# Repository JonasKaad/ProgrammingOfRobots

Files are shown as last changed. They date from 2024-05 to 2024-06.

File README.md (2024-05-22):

# Garage - Digital Twin

GitHub page for the "Programming of robots and other physical devices" project on the Software Engineering Master (elective) @ SDU F24

## Project

The project concerns itself with IoT and Digital Twins.

In it we have to design a physical and virtual representation of any given thing of our choice. We chose to design a garage. The specific requirements to the physical and virtual representation are as follows:

- Physical: ESP32 D1 Mini + Sensors/Actuators + 3D printing
- Virtual: Unity
- Communication: Wireless (UDP)

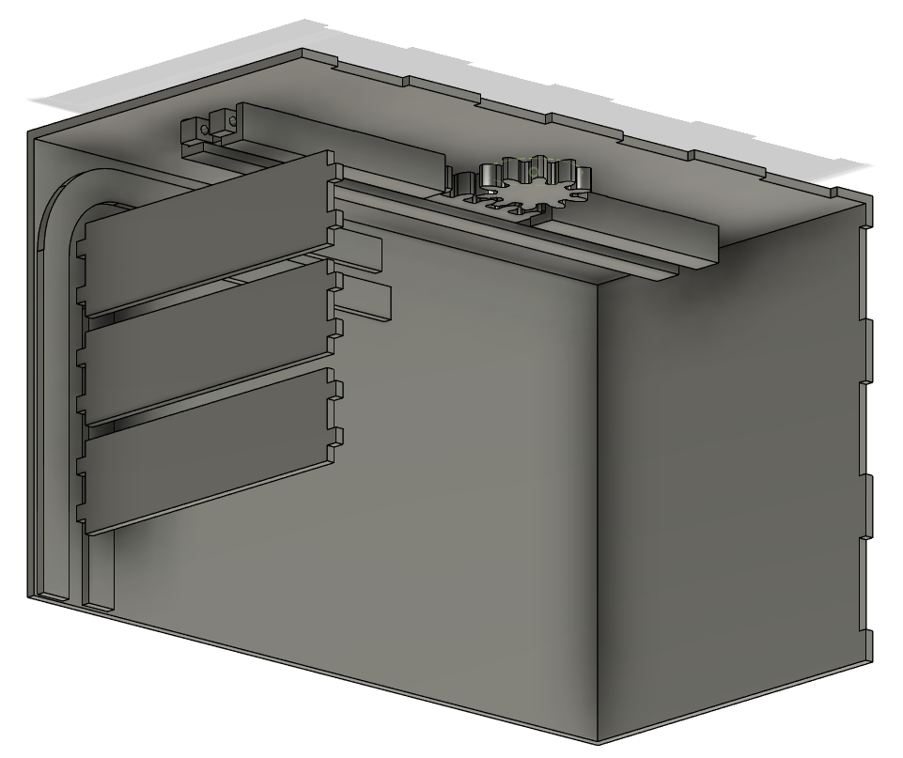
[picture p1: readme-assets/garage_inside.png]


## Repository

This repository contains all parts of the project:

- `src/`: C++ code for interacting with the ESP32 and the sensors, actuators, keypad and motors.
- `Unity/GarageTwin/`: All code related to the virtual representation of the digital twin, created in Unity
- `models/`: All 3D printed models, laser cut designs as well as a part lists to recreate the whole project.

## Authors

- [Jonas Solhaug Kaad](https://github.com/JonasKaad)
- [Victor Andreas Boye](https://github.com/VictorABoye)
- [Sebastian Christensen Mondrup](https://github.com/SebMon)
- [Alexander Vinding Nørup](https://github.com/AlexanderNorup)

**Supervisor**: Bjarke Kristian Maigaard Kjær Pedersen: bkp@mmmi.sdu.dk

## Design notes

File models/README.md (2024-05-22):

# Recreation of the garage


To recreate this project, you will need to 3D print the required parts, laser cut the garage and obtain

- `3DPrints/`: Contains all the `.STL` files that you need to 3D print.
- `LasercutDesigns/`: Contains all `.SVG` files that need to be lasercut. The design can be seen below
- All the electronic & hardware parts needed can be found below, with links to ArduinoTech, Harald Nyborg and Bauhaus.

## Electronic & hardware parts

- [ESP 32](https://arduinotech.dk/shop/live-d1-mini-esp32-development-board-based-esp8266/)
- [Breadboard](https://arduinotech.dk/shop/breadboard-830-points/)
- [DC Motor](https://arduinotech.dk/shop/n20-micro-metal-gear-motor/)
- [Motor Driver](https://arduinotech.dk/shop/mx1508-dc-motor-driver-module/)
- [LCD Screen](https://arduinotech.dk/shop/lcd-1602-16x2-w-pinheader/)
  - [LCD I2C Serial Interface](https://arduinotech.dk/shop/lcd-serial-interface/)
- [Battery Holder 4x AA](https://arduinotech.dk/shop/battery-holder-4-x-aa/)
- [4x AA Batteries](https://www.harald-nyborg.dk/kameda-alkaline-batteri-aa-10-pak)
- 12x [Buttons](https://arduinotech.dk/shop/switch-tactile-push-button-6x6x7mm/)
- [Potentiometer](https://arduinotech.dk/shop/potentiometer/)
- Cables
  - [Male-to-Male](https://arduinotech.dk/shop/65-stk-jump-wire-for-breadboard-and-arduino/)
  - [Male-to-Female](https://arduinotech.dk/shop/dupont-wire-30cm/)
- [3mm Screw](https://www.bauhaus.dk/gevindsskrue-uh-3x16)

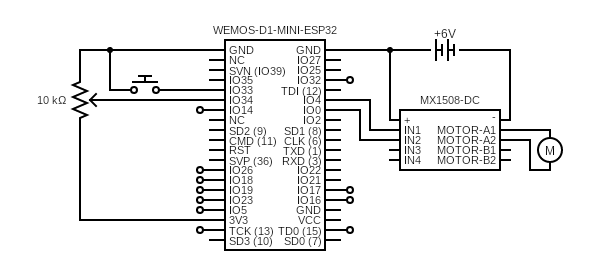
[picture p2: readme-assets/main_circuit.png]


## Laser cut designs

- Doors:

  

- Back:

  

- Roof:

  

- Left side:

  

- Right side:



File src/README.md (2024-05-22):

# Garage

## Pins

Below are the pins used on the ESP32 to connect to the keypad, screen and motors.

### Garage and motors

- POTENTIOMETER = 34
- DOOR_OPEN = 12
- DOOR_CLOSE = 27

### Keypad

- ZERO_PIN = 16
- ONE_PIN = 17
- TWO_PIN = 5
- THREE_PIN = 14
- FOUR_PIN = 23
- FIVE_PIN = 32
- SIX_PIN = 19
- SEVEN_PIN = 33
- EIGHT_PIN = 18
- NINE_PIN = 15
- RESET_PIN = 13
- ENTER_PIN = 26

### LCD Screen

- GND = Ground
- VCC = VCC
- SDA = 21
- SCL = 22

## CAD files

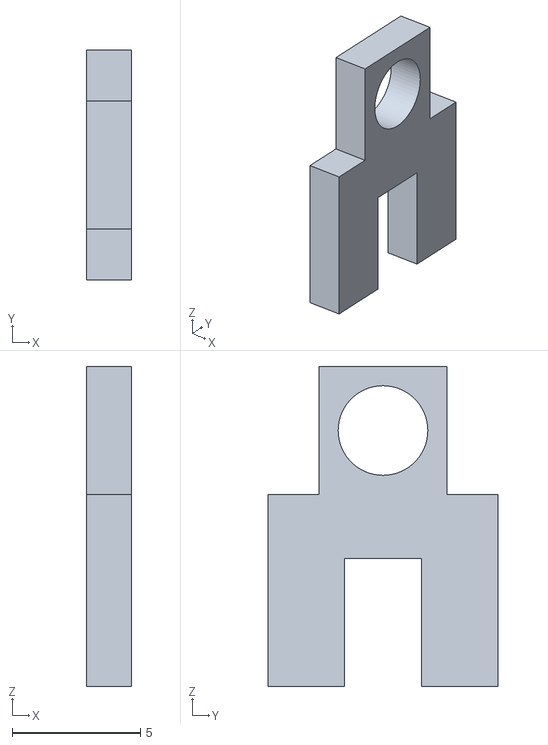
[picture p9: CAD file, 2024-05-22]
models/3DPrints/attachments/door_grapper.stl
1.75 x 9.00 x 12.5

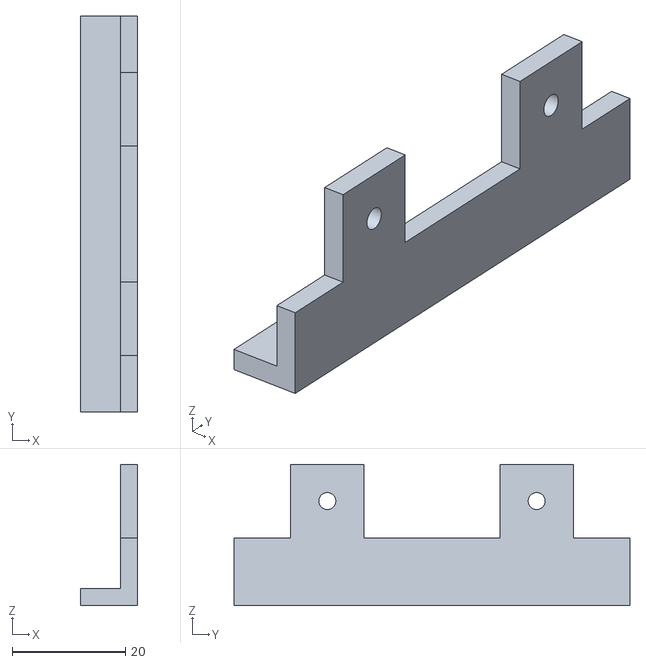
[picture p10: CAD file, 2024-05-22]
models/3DPrints/garage_bar/LBar_short.stl
10.0 x 70.0 x 25.0

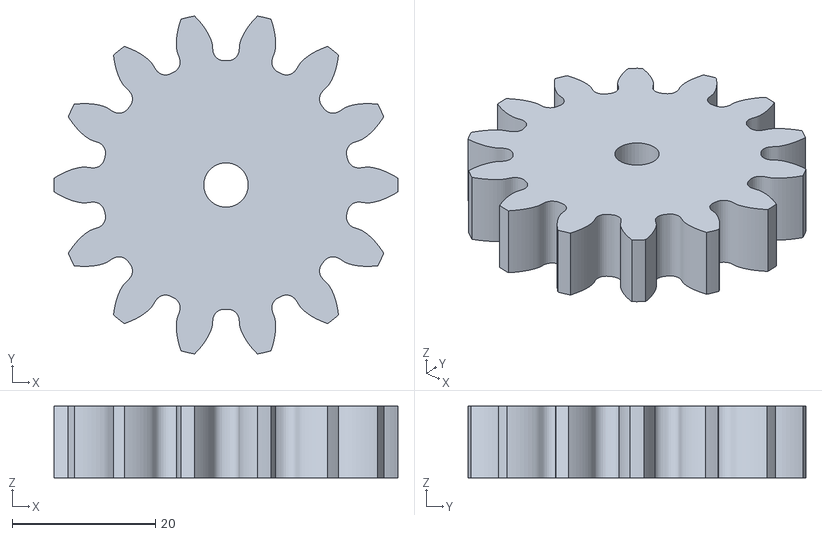
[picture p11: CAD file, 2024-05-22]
models/3DPrints/gears/potentiometer_gear.stl
48.0 x 47.2 x 10.0

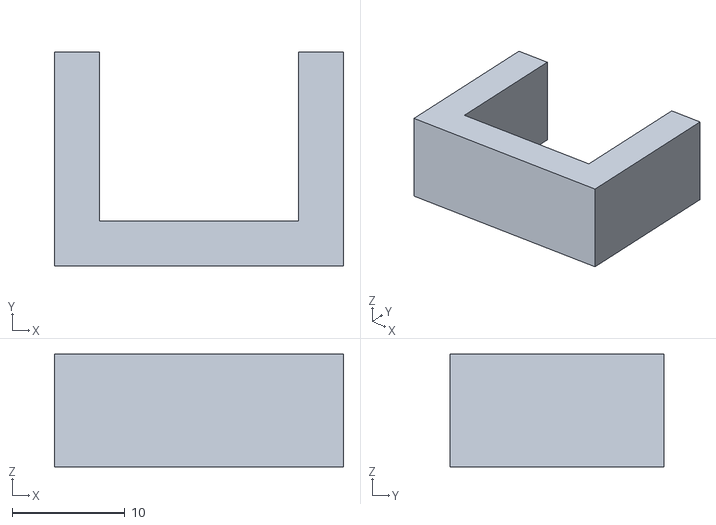
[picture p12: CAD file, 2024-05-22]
models/3DPrints/supports/potentiometer_casing.stl
25.6 x 19.0 x 10.0

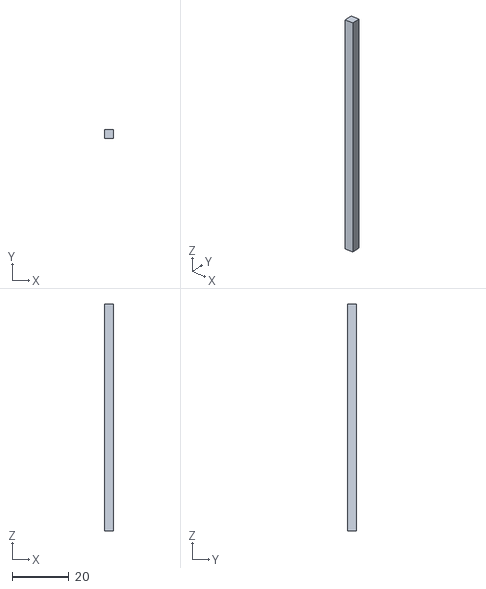
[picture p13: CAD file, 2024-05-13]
Unity/GarageTwin/Assets/Gears/WormDrive/long_stick.obj
3.00 x 3.00 x 80.0

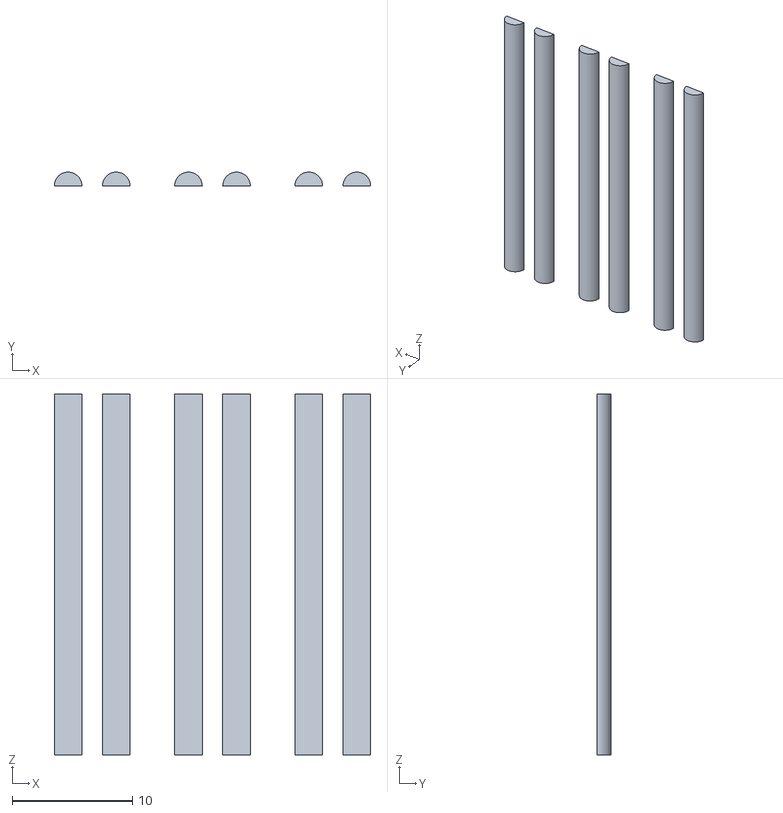
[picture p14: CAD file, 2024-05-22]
models/3DPrints/attachments/external_sticks_for_LBar.stl
26.3 x 1.15 x 30.0

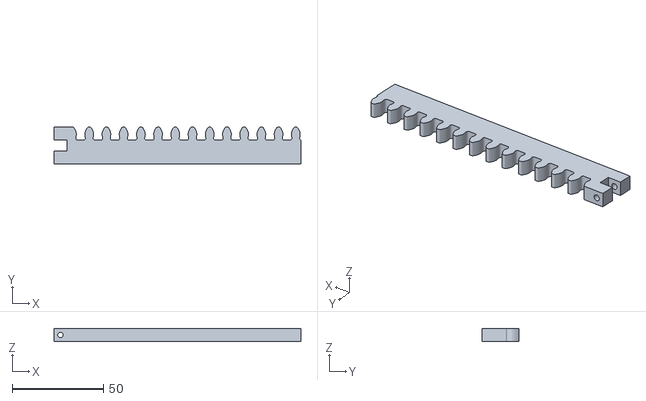
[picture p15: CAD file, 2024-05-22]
models/3DPrints/garage_bar/pinion_rack.stl
135.2 x 20.0 x 7.00

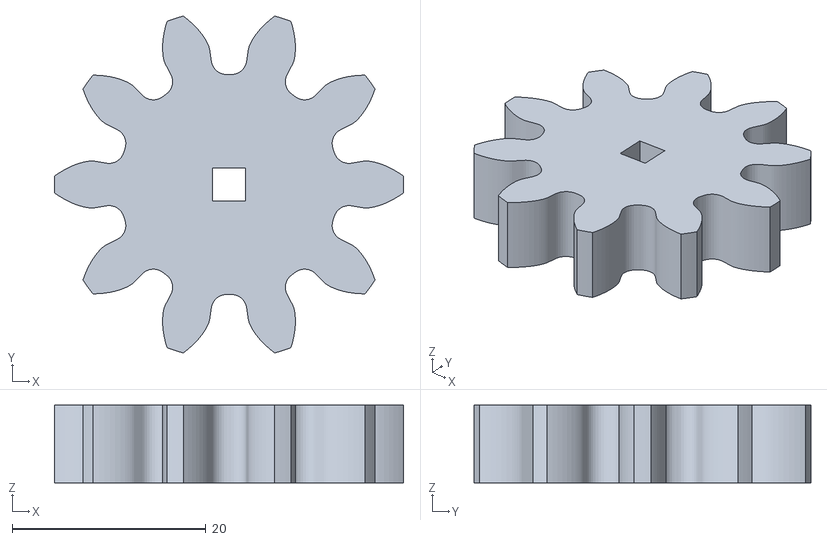
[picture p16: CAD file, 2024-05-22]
models/3DPrints/gears/gear_between_wormdrive_and_motor.stl
36.0 x 34.7 x 8.00

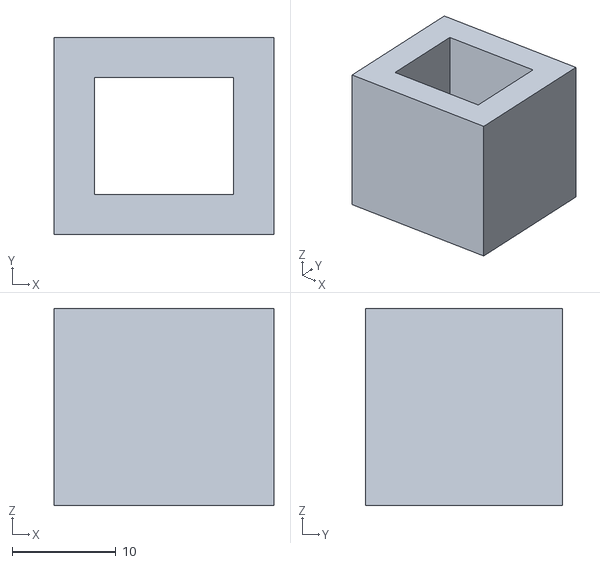
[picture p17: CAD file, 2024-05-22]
models/3DPrints/supports/motor_casing.stl
21.2 x 19.0 x 19.0

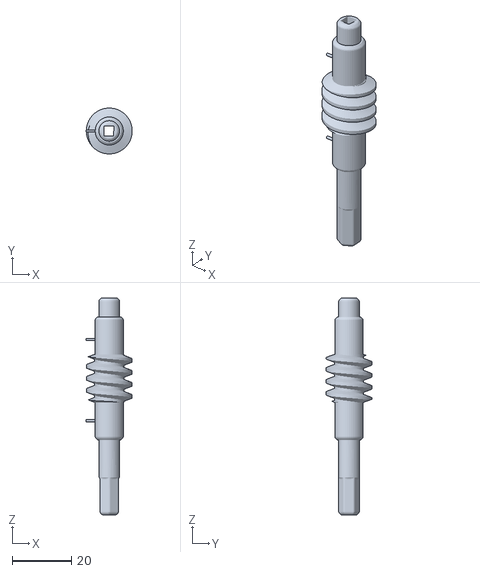
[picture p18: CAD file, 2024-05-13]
Unity/GarageTwin/Assets/Gears/WormDrive/worm_drive.obj
15.7 x 15.5 x 73.4

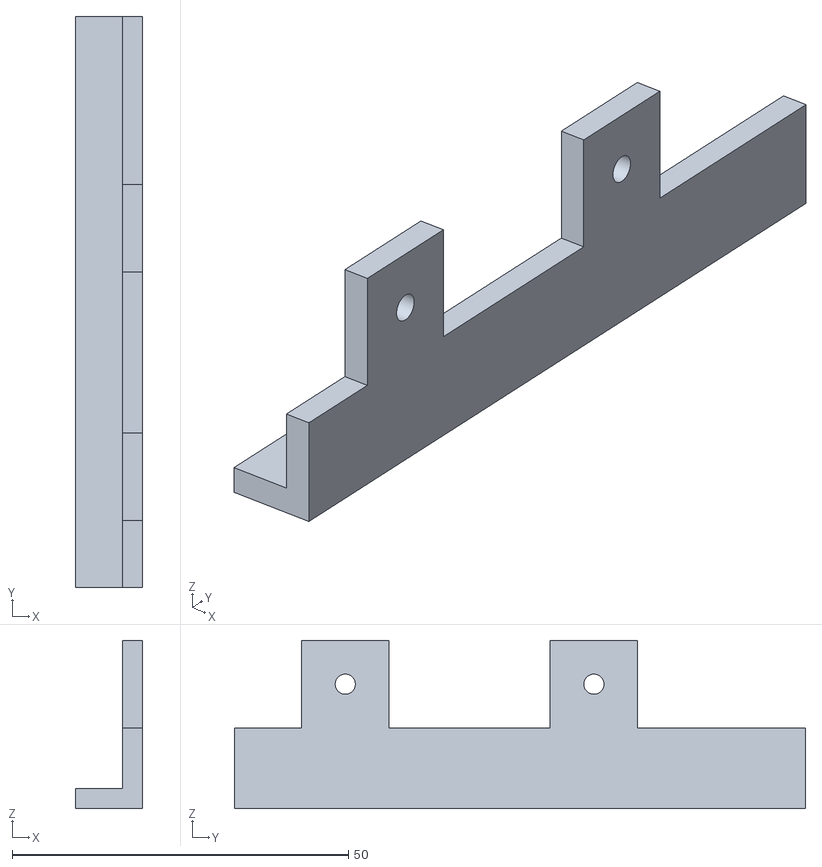
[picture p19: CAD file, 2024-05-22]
models/3DPrints/garage_bar/LBar_medium.stl
10.0 x 85.0 x 25.0

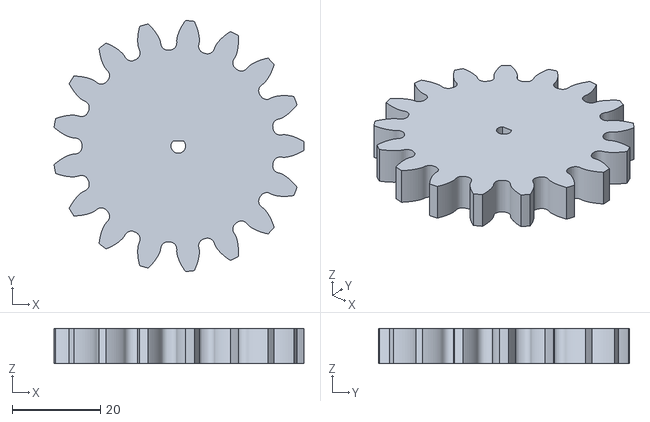
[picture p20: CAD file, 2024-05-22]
models/3DPrints/gears/motor_gear.stl
56.7 x 56.9 x 8.00

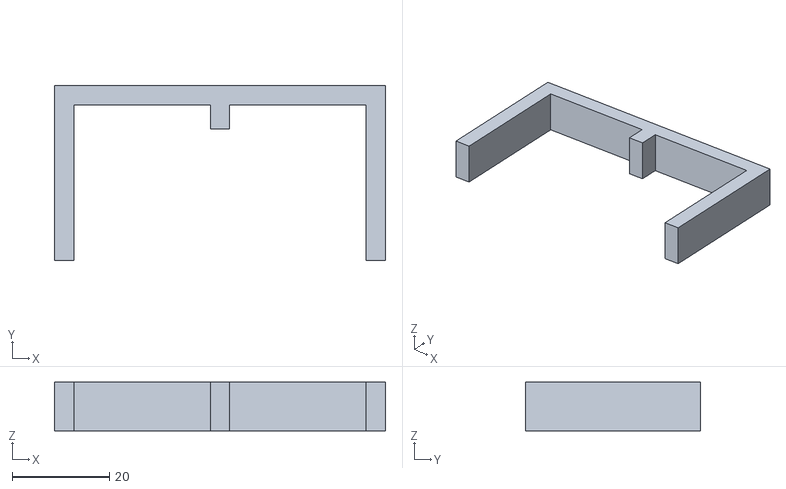
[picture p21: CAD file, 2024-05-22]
models/3DPrints/supports/wormdrive_pressure_holder.stl
68.0 x 36.0 x 10.0

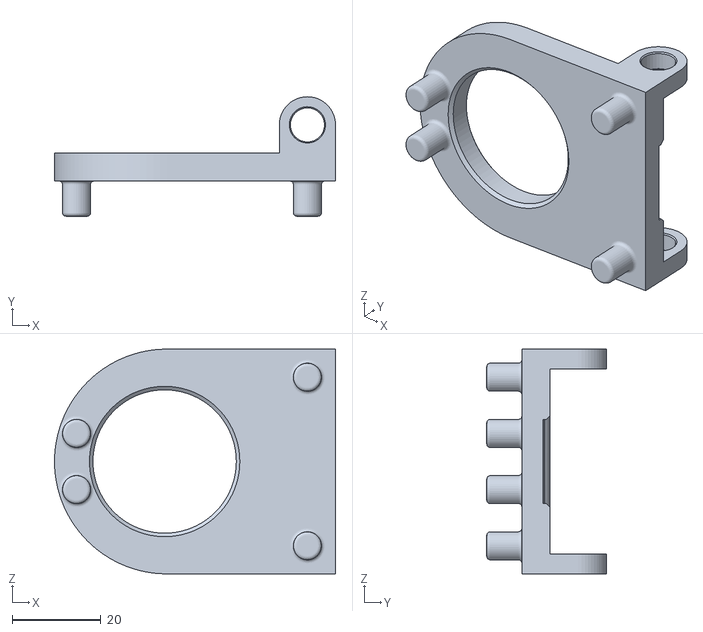
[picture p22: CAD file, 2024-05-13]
Unity/GarageTwin/Assets/Gears/WormDrive/worm_drive_support.obj
63.5 x 27.0 x 50.8

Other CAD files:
models/3DPrints/attachments/square_stick_for_wormdrive.stl
models/3DPrints/attachments/6_axle.stl
models/3DPrints/garage_bar/LBar_long.stl
models/3DPrints/gears/wormdrive_gear.stl
Unity/GarageTwin/Assets/Gears/WormDrive/lego_axle.obj
Unity/GarageTwin/Assets/Gears/WormDrive/worm_bar_gear.obj
models/3DPrints/attachments/door_connection_to_pinion.stl
models/3DPrints/attachments/internal_stick_for_pinion.stl
models/3DPrints/gears/drive_gear_on_top_of_wormdrive.stl
models/3DPrints/gears/pinion_gear.stl
models/3DPrints/gears/wormdrive.stl
models/3DPrints/supports/left_worm_drive_support.stl
models/3DPrints/supports/right_worm_drive_support.stl

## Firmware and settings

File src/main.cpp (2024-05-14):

#include <Arduino.h>
#include <LiquidCrystal_I2C.h>
#include <sstream>
#include <string>
#include <iostream>
#include <WiFi.h>
#include <WiFiUdp.h>
using namespace std;

// Digital Twin
const char SSID_NAME[] = "HotspotName";
const char SSID_PASSWORD[] = "mobilesoftware6";
WiFiUDP Udp;
char UDPPacketBuffer[255];

IPAddress RECEIVER_IP(192, 168, 125, 60); // 192.168.125.216
const int RECEIVER_PORT = 50195;
const int LOCAL_PORT = 3002;

char potUDPString[10] = {};
char keyUDPString[8] = {};

const int P_POT = 34;
const int DOOR_OPEN = 12;
const int DOOR_CLOSE = 27;

const int OPEN_LIMIT = 4095;
const int CLOSE_LIMIT = 500;

const int DOOR_LIMIT_BUFFER = 100;

int isOpen = 1;
int taskRunning = 0;

constexpr byte ZERO_PIN = 16;
constexpr byte ONE_PIN = 17;
constexpr byte TWO_PIN = 5;
constexpr byte THREE_PIN = 14;
constexpr byte FOUR_PIN = 23;
constexpr byte FIVE_PIN = 32;
constexpr byte SIX_PIN = 19;
constexpr byte SEVEN_PIN = 33;
constexpr byte EIGHT_PIN = 18;
constexpr byte NINE_PIN = 15;
constexpr byte RESET_PIN = 13;
constexpr byte ENTER_PIN = 26;

bool zeroPinState;
bool onePinState;
bool twoPinState;
bool threePinState;
bool fourPinState;
bool fivePinState;
bool sixPinState;
bool sevenPinState;
bool eightPinState;
bool ninePinState;
bool resetPinState;
bool enterPinState;

TaskHandle_t motor_handler;

int lcdColumns = 16;
int lcdRows = 2;

String inputString = String("");
const String password = String("1111");

const uint32_t KEYPAD_DELAY_TIME = 225;

LiquidCrystal_I2C lcd(0x27, lcdColumns, lcdRows);
void sendUdpData(String Data);
void sendMotorData(uint16_t motorVal);
void sendKeyData(int key);
void receiveUDPMessage();
void motorToggle(void *pvParameters);
void handleNumberInputs();
void setDoorState();
void keypadNumber(int key);
void sendKeyData(int key);
void handleEnter();
void handleReset();
void handleResetHelper();
void handleEnterHelper();



void setup()
{
  Serial.begin(9600);

  pinMode(ZERO_PIN, INPUT_PULLUP);
  pinMode(ONE_PIN, INPUT_PULLUP);
  pinMode(TWO_PIN, INPUT_PULLUP);
  pinMode(THREE_PIN, INPUT_PULLUP);
  pinMode(FOUR_PIN, INPUT_PULLUP);
  pinMode(FIVE_PIN, INPUT_PULLUP);
  pinMode(SIX_PIN, INPUT_PULLUP);
  pinMode(SEVEN_PIN, INPUT_PULLUP);
  pinMode(EIGHT_PIN, INPUT_PULLUP);
  pinMode(NINE_PIN, INPUT_PULLUP);
  pinMode(RESET_PIN, INPUT_PULLUP);
  pinMode(ENTER_PIN, INPUT_PULLUP);
  pinMode(DOOR_OPEN, OUTPUT);
  pinMode(DOOR_CLOSE, OUTPUT);

  lcd.init();
  lcd.backlight();

  WiFi.begin(SSID_NAME, SSID_PASSWORD);
  while (WiFi.status() != WL_CONNECTED)
  {
    Serial.println("Trying WiFi");
    delay(1000);
  }
  Udp.begin(LOCAL_PORT);

  setDoorState();
}

void loop()
{
  lcd.setCursor(0, 0);
  lcd.print("Enter Password: ");
  lcd.setCursor(0, 1);

  resetPinState = digitalRead(RESET_PIN);
  enterPinState = digitalRead(ENTER_PIN);

  if (enterPinState == LOW)
  {
    handleEnter();
  }

  else if (resetPinState == LOW)
  {
    handleReset();
  }
  else
  {
    handleNumberInputs();
  }
  receiveUDPMessage();
}

void handleResetHelper()
{
  inputString = "";
  lcd.clear();
  lcd.print(inputString);
  delay(KEYPAD_DELAY_TIME);
}

void handleEnterHelper()
{
  if (inputString == password)
  {
    lcd.clear();
    lcd.print("Correct");
    if (taskRunning == 1)
    {
      vTaskDelete(motor_handler);
    }
    xTaskCreate(motorToggle, "Toggle1", 4000, NULL, 1, &motor_handler);
    delay(3000);
  }
  else
  {
    lcd.clear();
    lcd.print("Wrong");
    delay(3000);
  }
  inputString = "";
  lcd.clear();
  lcd.print(inputString);
  delay(KEYPAD_DELAY_TIME);
}


void handleEnter()
{
  sendKeyData(-1);
  handleEnterHelper();
}

void handleReset()
{
  sendKeyData(-2);
  handleResetHelper();
}

void handleUDPKeypadNumber(int key)
{
  inputString += key;
  lcd.print(inputString);
  delay(KEYPAD_DELAY_TIME);
}

void handleNumberInputs()
{
  zeroPinState = digitalRead(ZERO_PIN);
  onePinState = digitalRead(ONE_PIN);
  twoPinState = digitalRead(TWO_PIN);
  threePinState = digitalRead(THREE_PIN);
  fourPinState = digitalRead(FOUR_PIN);
  fivePinState = digitalRead(FIVE_PIN);
  sixPinState = digitalRead(SIX_PIN);
  sevenPinState = digitalRead(SEVEN_PIN);
  eightPinState = digitalRead(EIGHT_PIN);
  ninePinState = digitalRead(NINE_PIN);

  if (zeroPinState == LOW)
  {
    keypadNumber(0);
  }
  else if (onePinState == LOW)
  {
    keypadNumber(1);
  }

  else if (twoPinState == LOW)
  {
    keypadNumber(2);
  }
  else if (threePinState == LOW)
  {
    keypadNumber(3);
  }

  else if (fourPinState == LOW)
  {
    keypadNumber(4);
  }
  else if (fivePinState == LOW)
  {
    keypadNumber(5);
  }

  else if (sixPinState == LOW)
  {
    keypadNumber(6);
  }
  else if (sevenPinState == LOW)
  {
    keypadNumber(7);
  }

  else if (eightPinState == LOW)
  {
    keypadNumber(8);
  }
  else if (ninePinState == LOW)
  {
    keypadNumber(9);
  }
}

void keypadNumber(int key)
{
  inputString += key;
  sendKeyData(key);
  lcd.print(inputString);
  delay(KEYPAD_DELAY_TIME);
}

void sendKeyData(int key)
{
  sprintf(keyUDPString, "key|%d", key);
  sendUdpData(keyUDPString);
}

void sendMotorData(uint16_t motorVal)
{
  float potPercentage = ((float)motorVal) / 4095;
  sprintf(potUDPString, "pot|%.2f", potPercentage);
  sendUdpData(potUDPString);
}


void motorToggle(void *pvParameters)
{
  taskRunning = 1;
  int target;
  int to_run;
  int not_run;

  if (isOpen == 1)
  {
    target = CLOSE_LIMIT;
    to_run = DOOR_OPEN;
    not_run = DOOR_CLOSE;
  }
  else
  {
    target = OPEN_LIMIT;
    to_run = DOOR_CLOSE;
    not_run = DOOR_OPEN;
  }

  digitalWrite(not_run, LOW);
  digitalWrite(to_run, HIGH);

  uint16_t x = analogRead(P_POT);

  while (abs(target - x) > DOOR_LIMIT_BUFFER)
  {
    x = analogRead(P_POT);
    sendMotorData(x);
    vTaskDelay(50);
  }
  digitalWrite(to_run, LOW);

  setDoorState();

  taskRunning = 0;
  vTaskDelete(motor_handler);
}

void setDoorState()
{
  uint16_t x = analogRead(P_POT);
  if (x > OPEN_LIMIT - DOOR_LIMIT_BUFFER)
  {
    isOpen = 1;
  }
  else if (x < CLOSE_LIMIT + DOOR_LIMIT_BUFFER)
  {
    isOpen = 0;
  }
}
void sendUdpData(String Data)
{
  Udp.beginPacket(RECEIVER_IP, RECEIVER_PORT);
  Udp.print(Data);
  Udp.endPacket();
}
//Receive UDP DataString from Unity
void receiveUDPMessage() {
  if (Udp.parsePacket()) {
    int length = Udp.read(UDPPacketBuffer, 255);
    if (length > 0) {
      UDPPacketBuffer[length] = 0;
    }

    // Parse the message 
    int value;
 
    if (UDPPacketBuffer != NULL) {
      value = atoi(UDPPacketBuffer); // Convert string to integer

      if(value<0){
        switch (value)
        {
        case -1:
          handleEnterHelper();
          break;
        case -2:
          handleResetHelper();
          break;
        default:
          handleResetHelper();
          break;
        }
      }
      else {
        handleUDPKeypadNumber(value);
      }
    }
  }
}

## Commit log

2024-05-13 SampleScene updated
2024-05-13 Add gears to model
    [lego_axle.obj, long_stick.obj, worm_bar_gear.obj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]
2024-05-13 Rotate gears when garage is opening or closing
2024-05-14 Added rotating gears for wormdrive
    [worm_drive_gearbase.obj]
2024-05-14 Fixed a bug that sent UDP message back when it received a message
    [main.cpp]
2024-05-21 Added readme for all models and added laser cut files
2024-05-21 Added all 3D print files
    [6_axle.stl, LBar_long.stl, LBar_medium.stl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]
2024-05-22 Re-added removed wormdrive and wormdrive gear
